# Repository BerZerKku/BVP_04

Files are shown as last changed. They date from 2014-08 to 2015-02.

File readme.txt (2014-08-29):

Плата BVP_04. 
Cделана в OrCAD 16.6.
Предназначена для работы в аппаратах Р400/Р400м/РЗСК/К400/ОПТИКА как со старыми
панелями, так и с новыми.

>>> v4
Сигналы RxBSP и TxBSP поменяны друг с другом.
На схеме найдена ошибка, сигнал управления МКУ закорочен на землю - т.е. речи нет и не будет.
Работает с платой KVP_03v3.
При работе с платой KVP_03v2 не будет работать ЦС.

>>> v3
Добавлена цифровая ретрансляция.
На схеме найдена ошибка, перепутаны местами сигналы RxBSP и TxBSP. 
Не использовать.
Работает с платой KVP_03v3.
При работе с платой KVP_03v2 не будет работать ЦС.

>>> v2 - СЕРИЯ
Входы управления подключены к 24В вместо земли.
Изменена подтяжка на +5В сигнала речи для варианта К400 (в варианте с речью, 
подтяжка идет к +5ВА).
Неиспользуемые входы микросхемы DD2 подтянуты к земле через резистор 10кОм.
Сделана возможность использования платы для Р400.
Немного передвинуты линии сигнализаций в верхней части.

>>> v1
Первая версия платы. 
На схеме имеются ошибки. 
Не использовать.

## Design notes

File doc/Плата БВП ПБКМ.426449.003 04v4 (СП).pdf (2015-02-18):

№ | Наименование | Корпус | Кол. | Поз. | Примечание
| | | | | ПБКМ.426449.003 ⁰
Изм | Лист | № докум. | Подп. | Дата
Разраб. | Щеблыкин М.В | | 18.02.15 | Плата БВП 04v4 Спецификация | Лит. | Лист | Листов
Провер. | Вершинин А.С. | | 18.02.15 | | | 1 | 4

### ООО «Прософт-Системы»

Н.контр. | Назаренко А.Н. | 18.02.15
Утв. | Чирков А.Г.
1 | Сборочный чертеж
| ПБКМ.426449.003 rev.0 | 1

ДЕТАЛИ
3 | Плата печатная
| BVP_04v4 | 1

ПРОЧИЕ ИЗДЕЛИЯ

Диоды

5 | BAT54A | SOT-23_3 | 1 | VD18
6 | Светодиод KP-2012SGC
| зеленый KINGBRIGHT | 0805 | 2 | VD19,VD20
7 | Светодиод FYL-5013PURD1C
| красный FORYARD | 2 pins | 2 | VD15,VD16
9 | Светодиод L-53SGD зеленый
| KINGBRIGHT | 2 pins | 1 | VD14
13 | Дроссель LQH43CN100K03L
| 10мкГн 650мА MURATA | 1812 | 2 | L2,L3
15 | Кварцевый резонатор KX-K 20МГц
| планарный -20°/+70°С GEYER | SMD_2 | 1 | ZQ1

Конденсаторы

16 | 0805 NP0 50В 22пФ ±5% | 0805 | 2 | C39,C40

# ПБКМ.426449.003

Лист

2 Изм | Лист | № докум. | Подп. | Дата
19 | 0805 X7R 50В 0.1мкФ ±10% | 0805 | 18 | C3,C6,C29-C31,C33-C36,C38,C41-C48
23 | 0805 X7R 10В 10мкФ ±10% | 0805 | 3 | C28,C32,C49

Микросхемы

29 | ADuM3402ARWZ AD | SOIC_16 | 2 | DD4,DD7
30 | ATmega164P-20AU ATMEL | TQFP_44 | 1 | DD6
31 | SN74ACT573DW(R) TI
| (74ACT573SC FAIRCHILD,
| M74HCT573M1R(RM13TR) ST) | SOIC_20 | 2 | DD1,DD2
33 | SN74LVC1G14DBV(R, T) TI
| (74LVC1G14GV PANASONIC, NXP) | SOT-23_5 | 1 | DD5
41 | Преобразователь напряжения
| TMA 0505S 1Вт +5В TRACO | SIP7_4 | 1 | DA6
45 | Оптрон HCPL-817-300E AVAGO | SMD_4 | 7 | AV1-AV7

Разъемы

48 | Вилка на плату IDC-10M | IDC_10 | 1 | X6 | 2.54мм
49 | DIN41612 09031966921 HARTING
| (DIN 41612 3*32 96 MR) | 96 pins | 2 | X1,X2 | вилка угловая
51 | PLS-2 | PLS_2 | 2 | X3,X4
| Резисторы
53 | 0805 0Ом | 0805 | 2 | R67,R69
55 | 0805 51Ом ±5% | 0805 | 6 | R38-R40,R45-R47
59 | 0805 510Ом ±5% | 0805 | 6 | R9,R11,R12,R42-R44
61 | 0805 1кОм ±5% | 0805 | 4 | R6,R41,R60,R61
63 | 0805 2кОм ±5% | 0805 | 7 | R13-R19

| | | | 3 Изм
Лист | № докум. | Подп. | Дата
65 | 0805 5.1кОм ±5% | 0805 | 2 | R7,R8
67 | 0805 10кОм ±5% | 0805 | 10 | R49-R53,R62-R66
73 | сборка 1206х4 100 ±5% | 1206 | 6 | RR1,RR2,RR6-RR9 | convex
75 | сборка 1206x4 10кОм ±5% | 1206 | 3 | RR3-RR5 | convex

Супрессоры

79 | SM6T6V8CA 6.8В двунаправен. | DO-214AA | 1 | VD1
81 | SM6T30CA 30В двунаправленный | DO-214AA | 1 | VD2

| | | | 4 Изм
Лист | № докум. | Подп. | Дата

### Лист регистрции ревизий СП

№ ревизии | № замененных (измененных) страниц | Дата ревизии | Краткое содержание и причина внесения изменений | Примечание
0 | вновь | 18.02.15 | На замену «АВАНТ БВП v4.4»

Исполнения:
Плата распаивается только в одном варианте, для К400.

### Лист регистрции ревизий СБ

№ ревизии | № замененных (измененных) страниц | Дата ревизии | Краткое содержание и причина внесения изменений | Примечание
0 | вновь | 18.02.15 | На замену «АВАНТ БВП v4.4»

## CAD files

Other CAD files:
doc/Плата БВП ПБКМ.426449.003 04v4 (СБ).dwg

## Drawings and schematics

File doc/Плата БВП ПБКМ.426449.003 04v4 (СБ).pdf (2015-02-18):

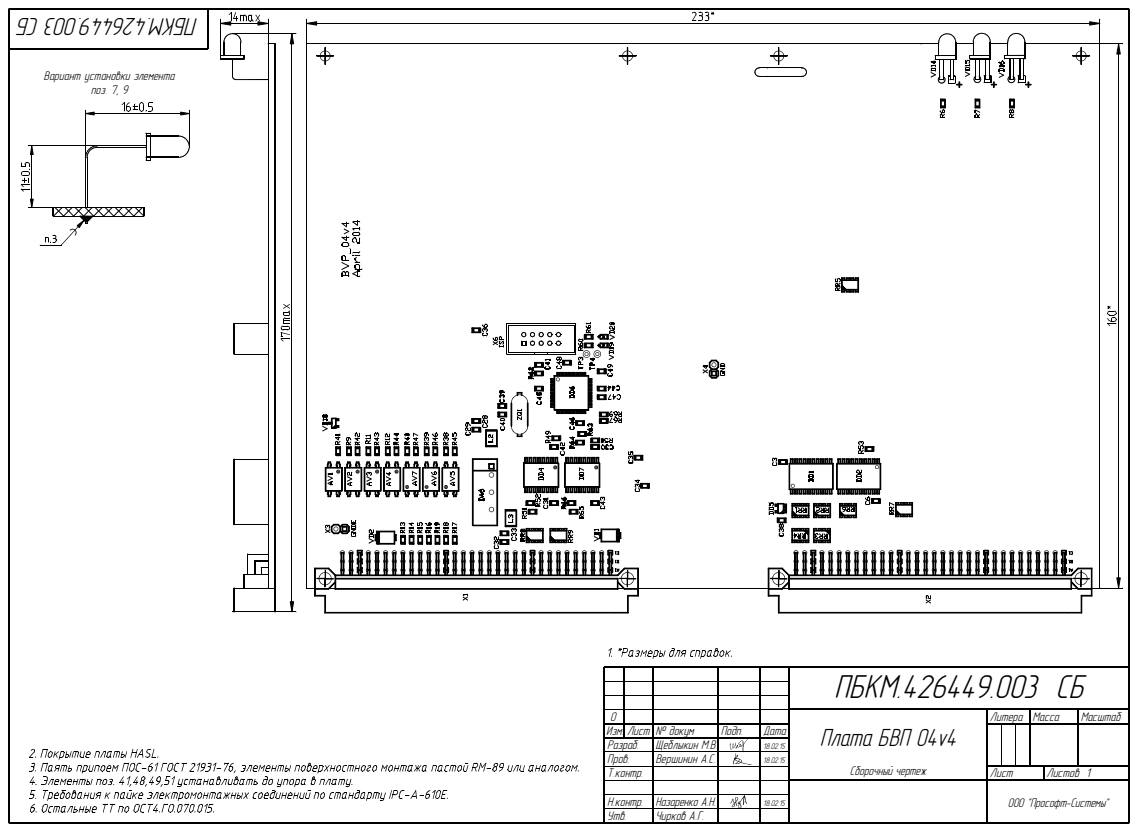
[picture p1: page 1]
Ëèñòîâ 1; Ìàññà; Ìàñøòàá; Ïîäï.; Äàòà; Óòâ.; Í.êîíòð.; Ò.êîíòð.; Ïðîâ.; Ðàçðàá.; Èçì. Ëèñò; ×èðêîâ À.Ã.; Íàçàðåíêî À.Í.; Âåðøèíèí À.Ñ.; Ùåáëûêèí Ì.Â.; № äîêóì; Ëèñò; Ëèòåðà; ÏÁÊÌ.426449.003 ÑÁ; Ïëàòà ÁÂÏ 04v4; ïîç. 7, 9

Âàðèàíò óñòàíîâêè ýëåìåíòà

Ñáîðî÷íûé ÷åðòåæ

ÎÎÎ "Ïðîñîôò-Ñèñòåìû"

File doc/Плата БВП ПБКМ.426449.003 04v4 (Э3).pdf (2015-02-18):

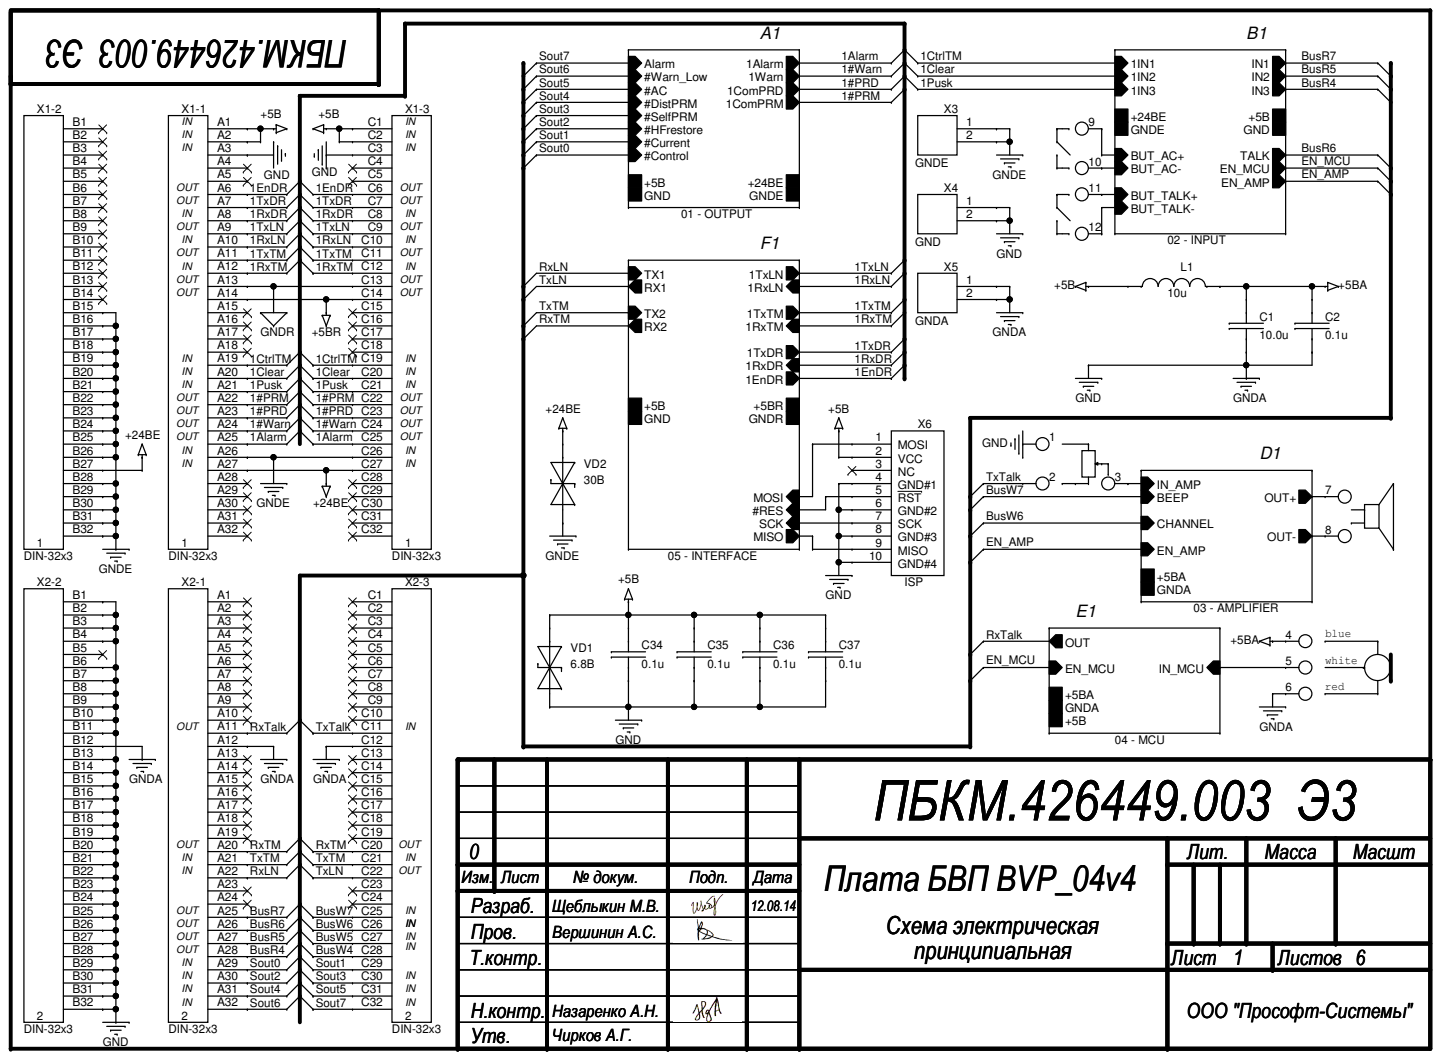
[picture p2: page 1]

ПБКМ.426449.003 Э3 ПБКМ.426449.003 Э3 ПБКМ.426449.003 Э3

0 | | | | | Плата БВП BVP_04v4 Плата БВП BVP_04v4 Плата БВП BVP_04v4 Схема электрическая Схема электрическая Схема электрическая | Лит. | Масса Масса Масса | Масшт Масшт Масшт
Изм. Изм. Изм. | Лист Лист Лист | № докум. № докум. № докум. | Подп. Подп. Подп. | Дата Дата Дата
Разраб. Разраб. Разраб. | | Щеблыкин М.В. Щеблыкин М.В. Щеблыкин М.В. | | 12.08.14 12.08.14 12.08.14
Пров. Пров. Пров. | | Вершинин А.С. Вершинин А.С. Вершинин А.С.
принципиальная Т.контр. принципиальная Т.контр. принципиальная Т.контр. | Лист Лист Лист 1 6 1 6 1 6 | Листов Листов Листов

Н.контр. Н.контр. Н.контр. | Назаренко А.Н. Назаренко А.Н. Назаренко А.Н.
Утв. Утв. Утв. | Чирков А.Г. Чирков А.Г. Чирков А.Г.

ООО "Прософт-Системы" ООО "Прософт-Системы" ООО "Прософт-Системы"

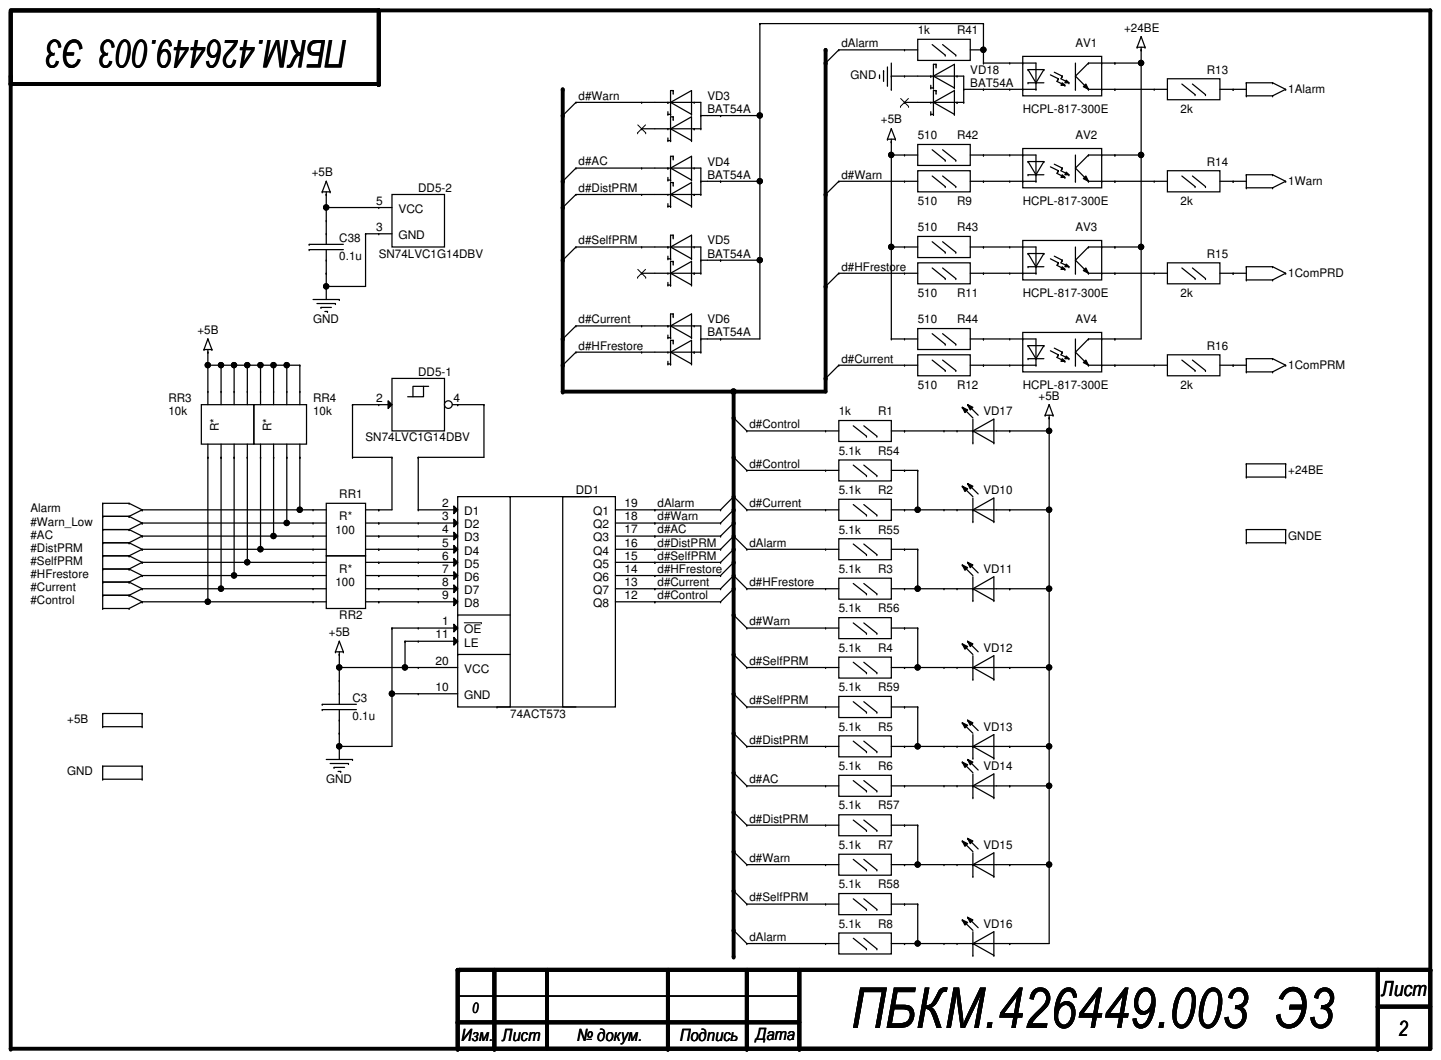
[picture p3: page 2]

Лист ПБКМ.426449.003 Э3 Лист ПБКМ.426449.003 Э3 Лист ПБКМ.426449.003 Э3 2 ⁰ Изм. 2 ⁰ Изм. 2 ⁰

Лист | № докум. | Подпись | Дата

Изм. | Лист | № докум. | Подпись | Дата

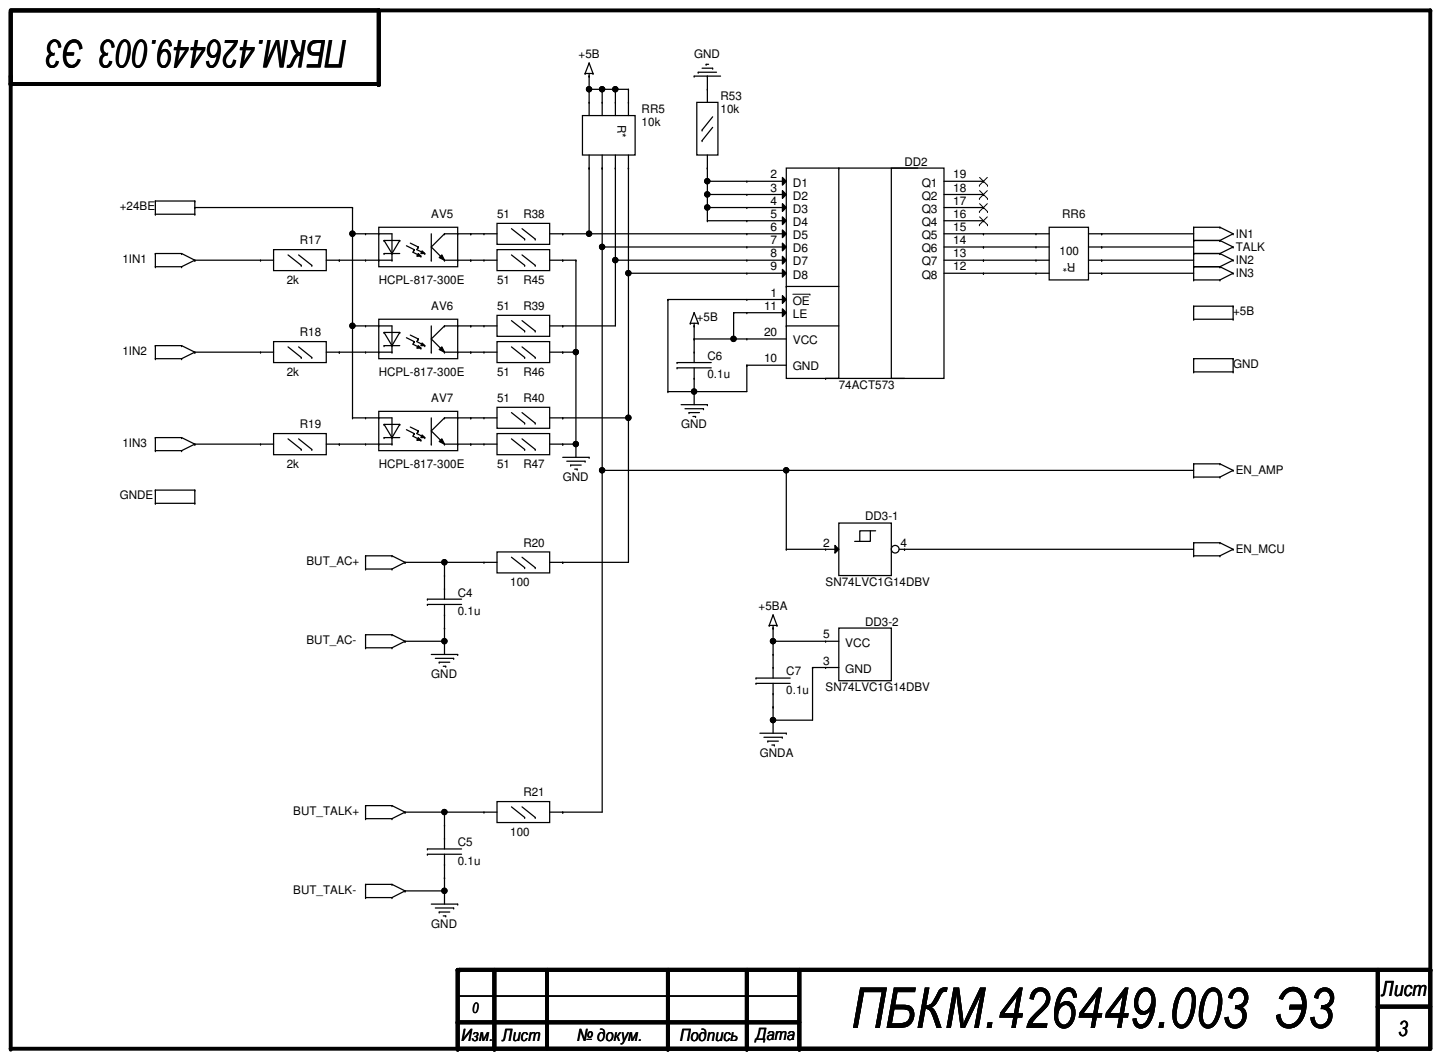
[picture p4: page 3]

Лист ПБКМ.426449.003 Э3 Лист ПБКМ.426449.003 Э3 Лист ПБКМ.426449.003 Э3 3 ⁰ Изм. 3 ⁰ Изм. 3 ⁰

Лист | № докум. | Подпись | Дата

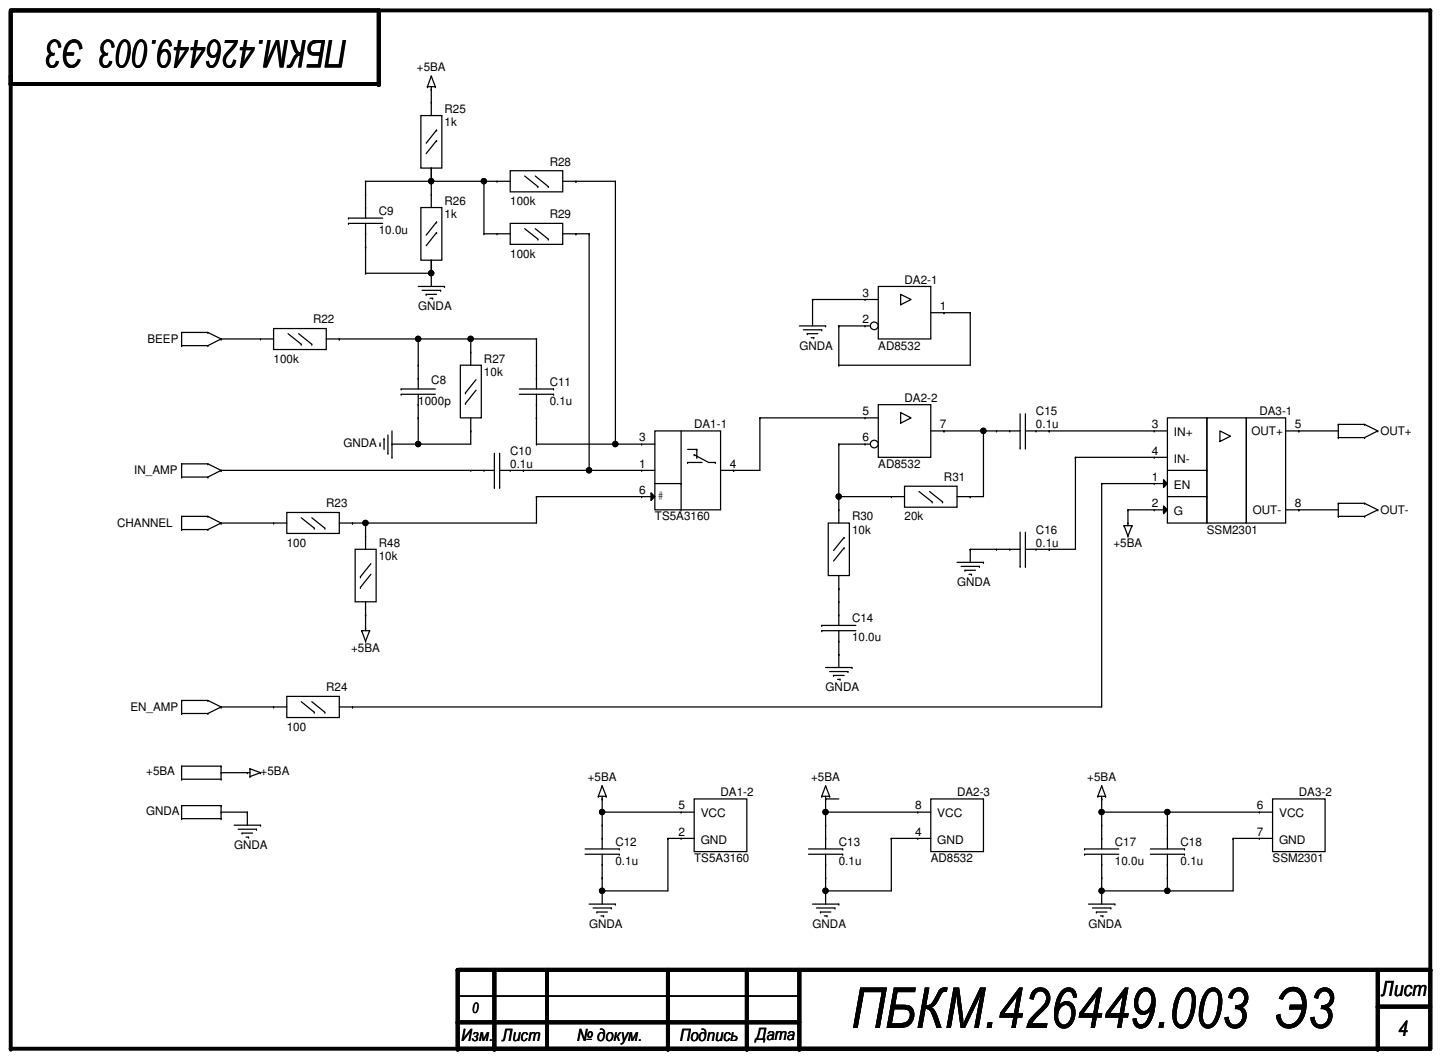
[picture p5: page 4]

Лист ПБКМ.426449.003 Э3 Лист ПБКМ.426449.003 Э3 Лист ПБКМ.426449.003 Э3 4 ⁰ Изм. 4 ⁰ Изм. 4 ⁰

Лист | № докум. | Подпись | Дата

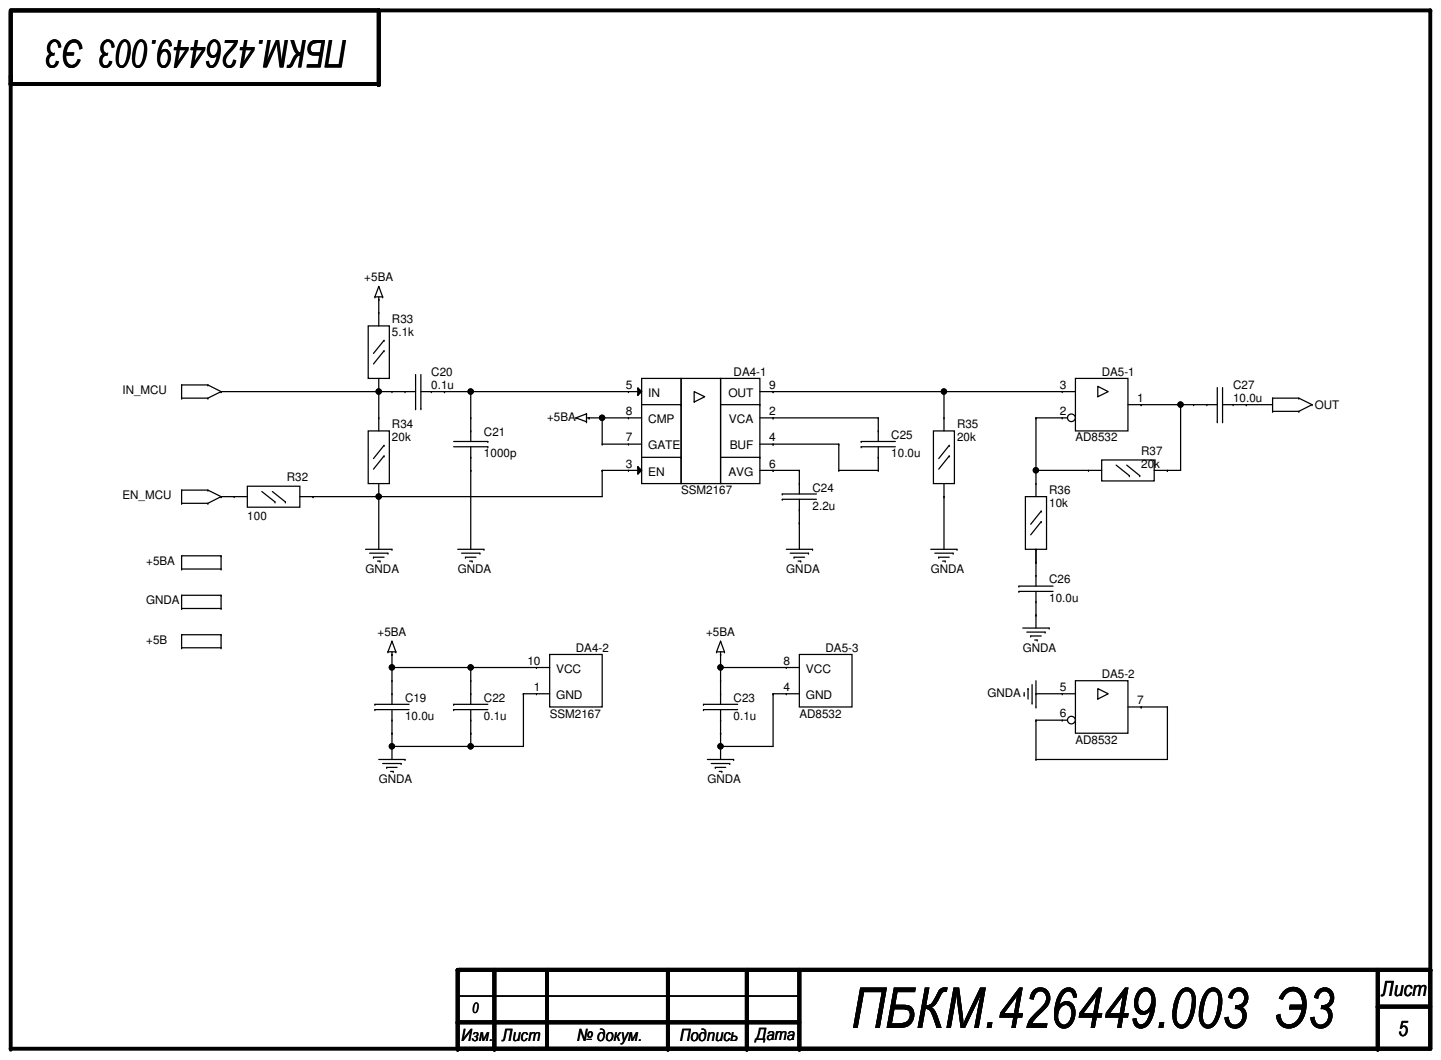
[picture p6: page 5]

Лист ПБКМ.426449.003 Э3 Лист ПБКМ.426449.003 Э3 Лист ПБКМ.426449.003 Э3 5 ⁰ Изм. 5 ⁰ Изм. 5 ⁰

Лист | № докум. | Подпись | Дата

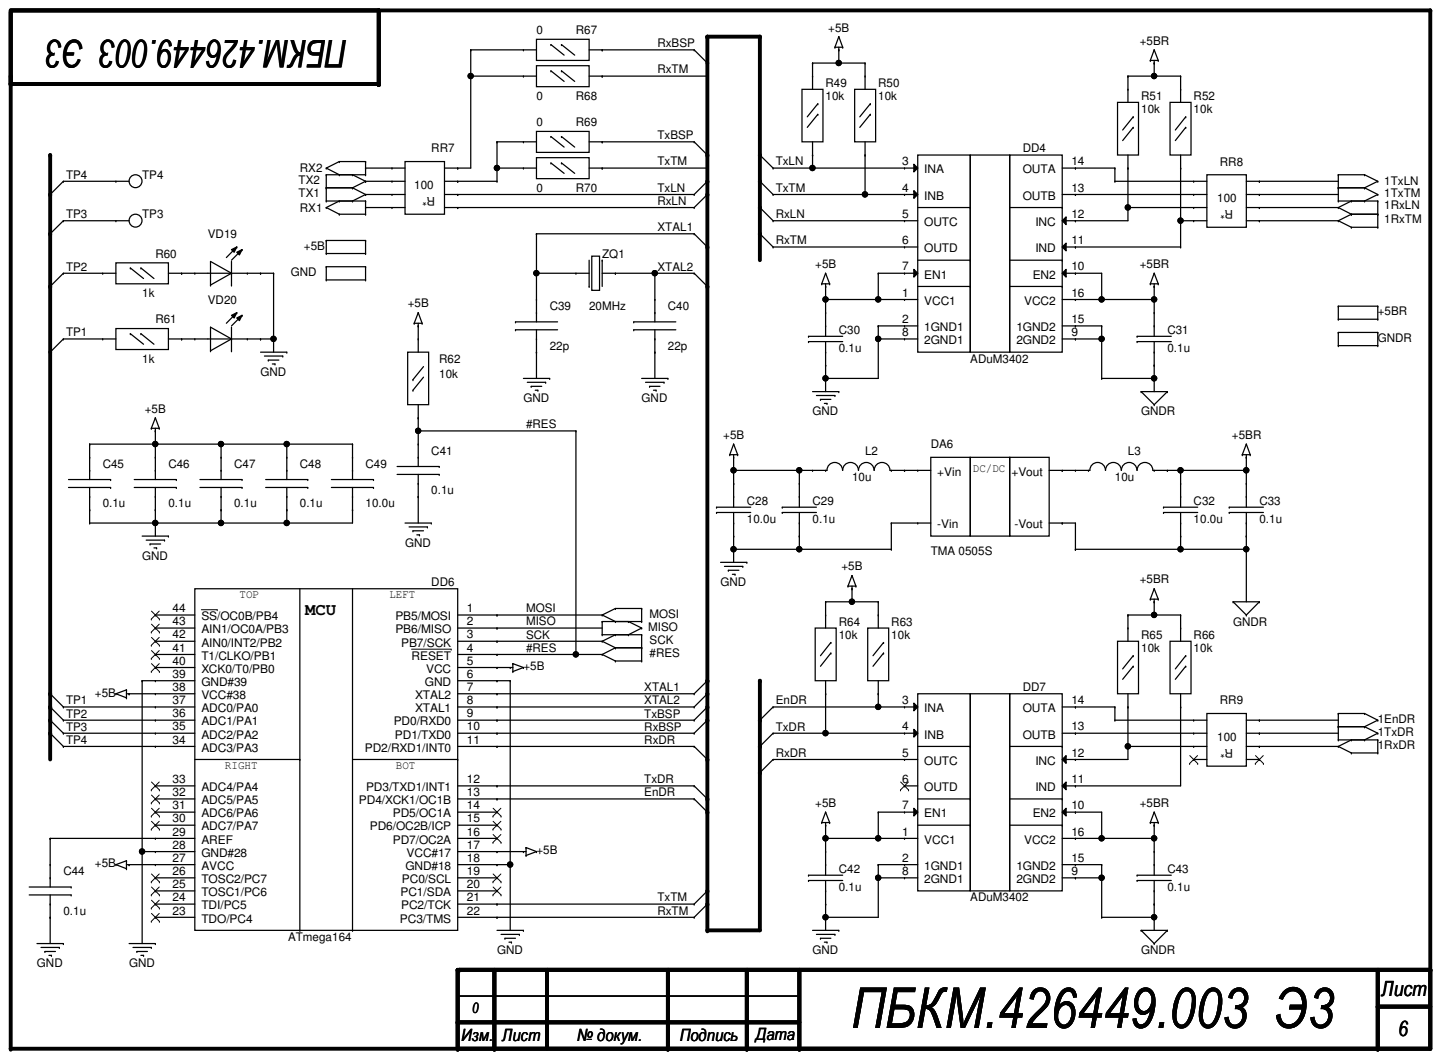
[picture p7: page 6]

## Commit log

2014-08-04 Вновь.
2014-08-04 Добавлены файлы проекта.
    [BVP_04V1.brd, nc_param.txt, Плата БВП BVP_04v1 (СБ).dwg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]
2014-08-04 Добавлена схема. Подправлено описание.
    [BVP_04V1.DSN]
2014-08-04 Исправлен файл описания.
2014-08-04 Версия 4. На плате исправлены сигналы RxBSP и TxBSP.
    [BVP_04V3.DSN, BVP_04V3.brd, BVP_04V4.DSN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]
2014-08-04 Исправлена схема и переразведена плата. Подготовлена документация для производства.
    [BVP_04V3.DSN, BVP_04V3.brd, BVP_04V4.DSN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]
2014-08-04 Исправлены герберы, до этого не был обновлен слой шелкографии.
    [BVP_04V4.brd]
2014-08-04 Обновлен файл просмотра герберов (?!).
2014-08-04 Добавлены документы в pdf.
    [Плата БВП BVP_04v4 (СБ).dwg]
2014-08-12 СП 1v0 СБ 1v0 Из-за ошибки в схеме включения МКУ убраны вариантные исполнения. Плата распаивается только для К400. Со сборочного чертежа убраны лишние элементы. Добавлены файлы для автоматического фо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
    [BVP_04V4.DSN, Плата БВП BVP_04v4 (СБ).dwg]
2014-08-29 На схеме и соответственно плате найдена ошибка, закорочен сигнал управления МКУ. Т.е. речи нет.
2015-02-18 На схему добавлены рамки. Изменен децимальный номер.
    [BVP_04V4.DSN, Плата БВП BVP_04v4 (СБ).dwg, Плата БВП ПБКМ.426449.003 04v4 (СБ).dwg]
